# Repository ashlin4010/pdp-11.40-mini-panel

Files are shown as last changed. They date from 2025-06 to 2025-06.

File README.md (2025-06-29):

# PDP-11/40 Mini Panel (Unfinished)
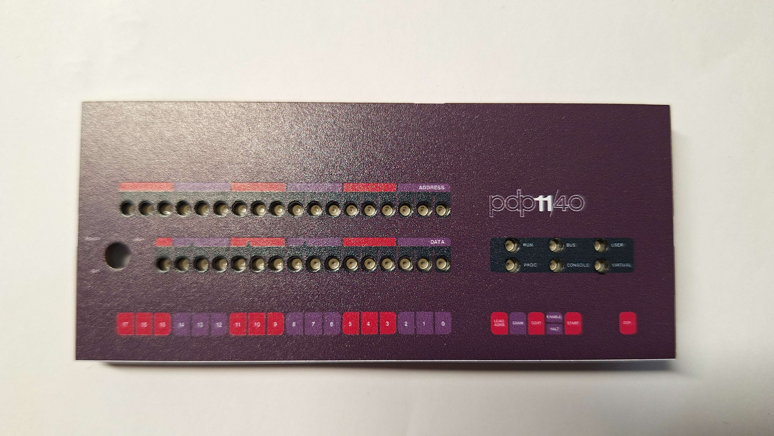
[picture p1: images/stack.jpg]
mini front panel


Included in this repository are the PCB files to make a miniature PDP-11/40 front panel. The board uses a XIAO nrf52840 dev board. No software has been written yet.

# Ordering pcbs
This project consists of three pcbs:
- A faceplate - Decorative only
    - pdp-11-colour.zip
    - 2 layers
    - PCB Color: White
    - Silkscreen Technology: EasyEDA multi-color silkscreen
- Main PCB - Has all electronics
    - pdp-11-pcb.zip
    - 4 layers
- Spacer PCB (Optional) - Removes the need for hot air
    - XIAO-nRF52840-spacer_thin.zip
    - 2 layers
    - Thickness: 0.8m
    - Deburring/Edge rounding: No

# Building
Place the spacer on the back of the nrf52840 module with the pads facing the the front. Solder the spacer to the back of the module using a minimal amount of solder. File the solder pints flat if needed.

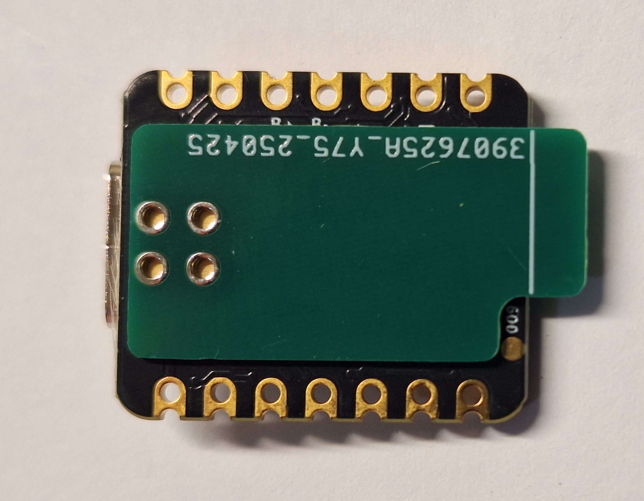
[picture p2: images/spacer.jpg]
pcb spacer


Solder the module and spacer to the main PCB. Using some short wire solder the pads of the space to the main PCB. Skip the top most pad, its ground.

For the programming header orientation check [main pcb image](/images/pcb_back.jpg).

# Programming
¯\\_(ツ)_/¯

# BOM

| Quantity | Part | Link |
|---|---|---|
| 1 | mini nrf52840 | https://www.aliexpress.com/item/1005008563470913.html |
| 1 | 3.3V 1A SOT-223 Reg | https://www.digikey.co.nz/en/products/detail/texas-instruments/TLV1117LV33DCYR/2666508 |
| 40 | Red LED LSP47K | https://www.digikey.co.nz/en/products/detail/ams-osram-usa-inc/LS-P47K-H1K2-1-0-2-R18-Z/1227985 |
| 2 | 1uf 0805 | https://www.digikey.co.nz/en/products/detail/samsung-electro-mechanics/CL21B105KAFNNNE/3886724  |
| 5 | 74HC595PW | https://www.digikey.co.nz/en/products/detail/nexperia-usa-inc/74HC595PW-118/946653 |
| 40 | 150R 0805 | https://www.digikey.co.nz/en/products/detail/yageo/RC0805JR-07150RL/728255 |
| 2 | 100R 0805 | https://www.digikey.co.nz/en/products/detail/yageo/RC0805JR-10100RL/14286702 |
| 1 | Programming Header  | https://www.digikey.co.nz/en/products/detail/adafruit-industries-llc/4048/9843412 |
| 1 | Expansion Header | https://www.digikey.co.nz/en/products/detail/adam-tech/HRS-2C-16-G-SMT-P/10245144 |

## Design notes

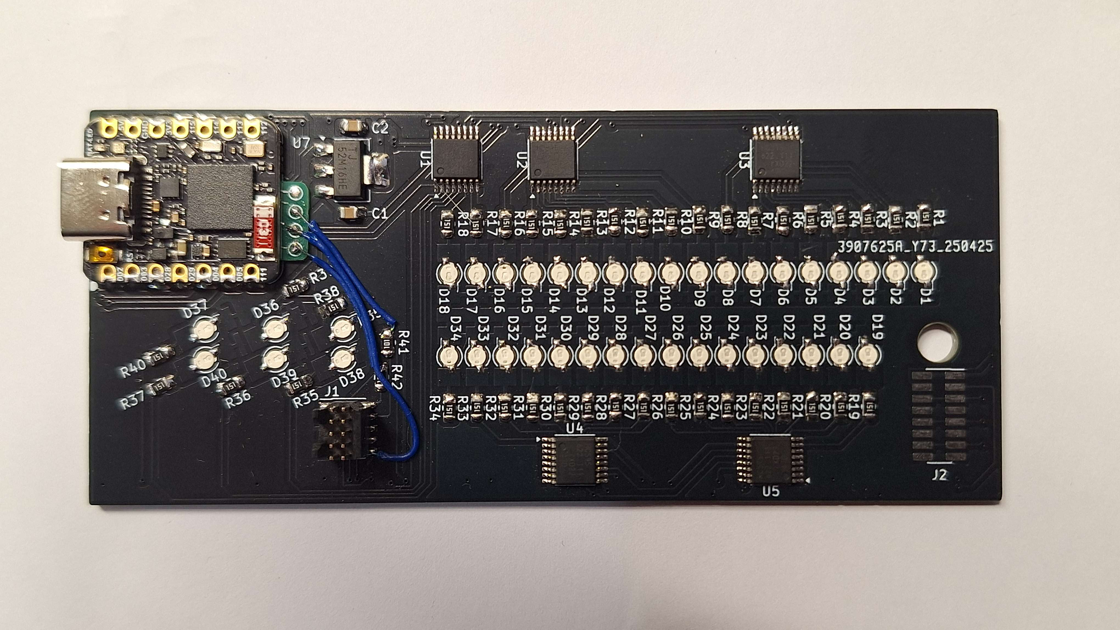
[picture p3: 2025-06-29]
images/pcb_back.jpg

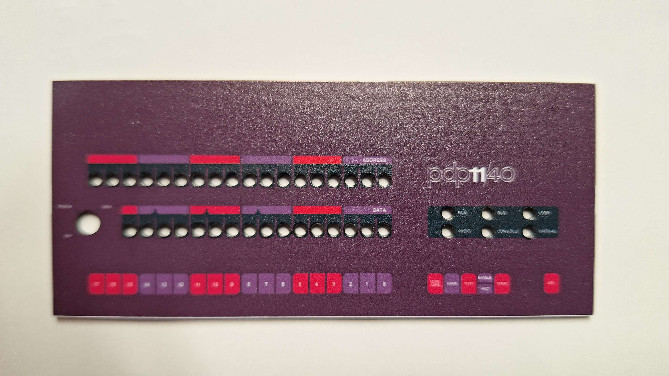
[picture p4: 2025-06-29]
images/faceplate.jpg

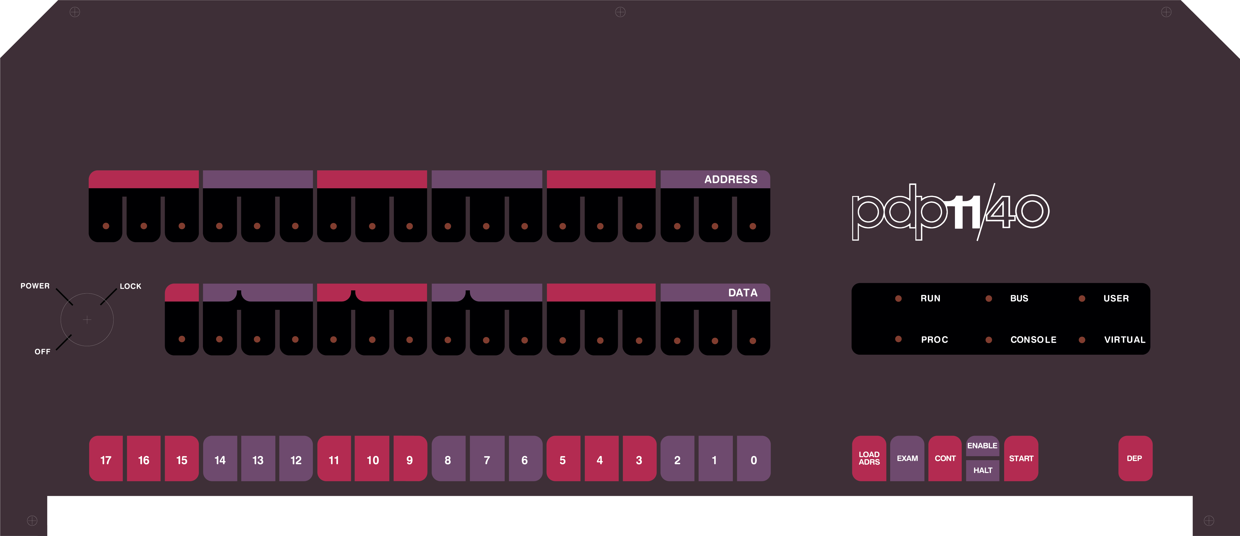
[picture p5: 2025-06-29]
art/PDP11.40_ref.png

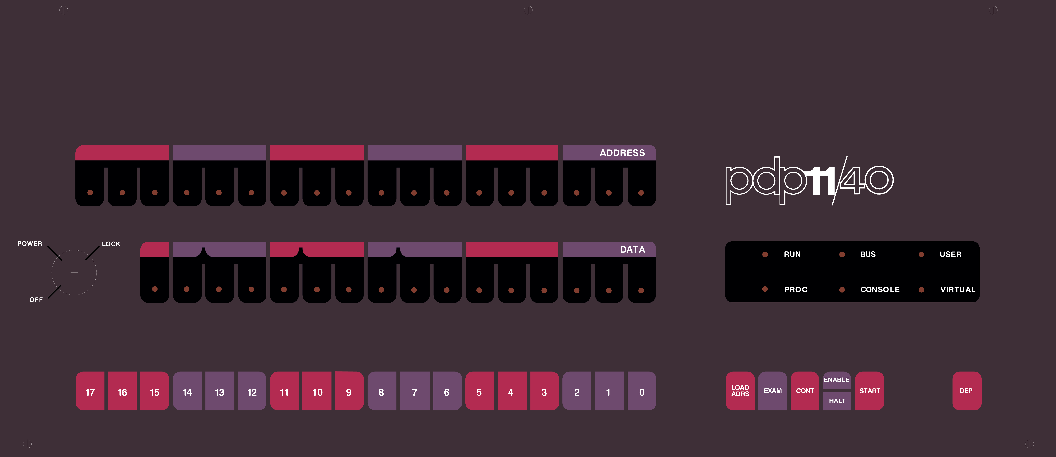
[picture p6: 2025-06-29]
art/PDP11.40_panel_600dpi.png

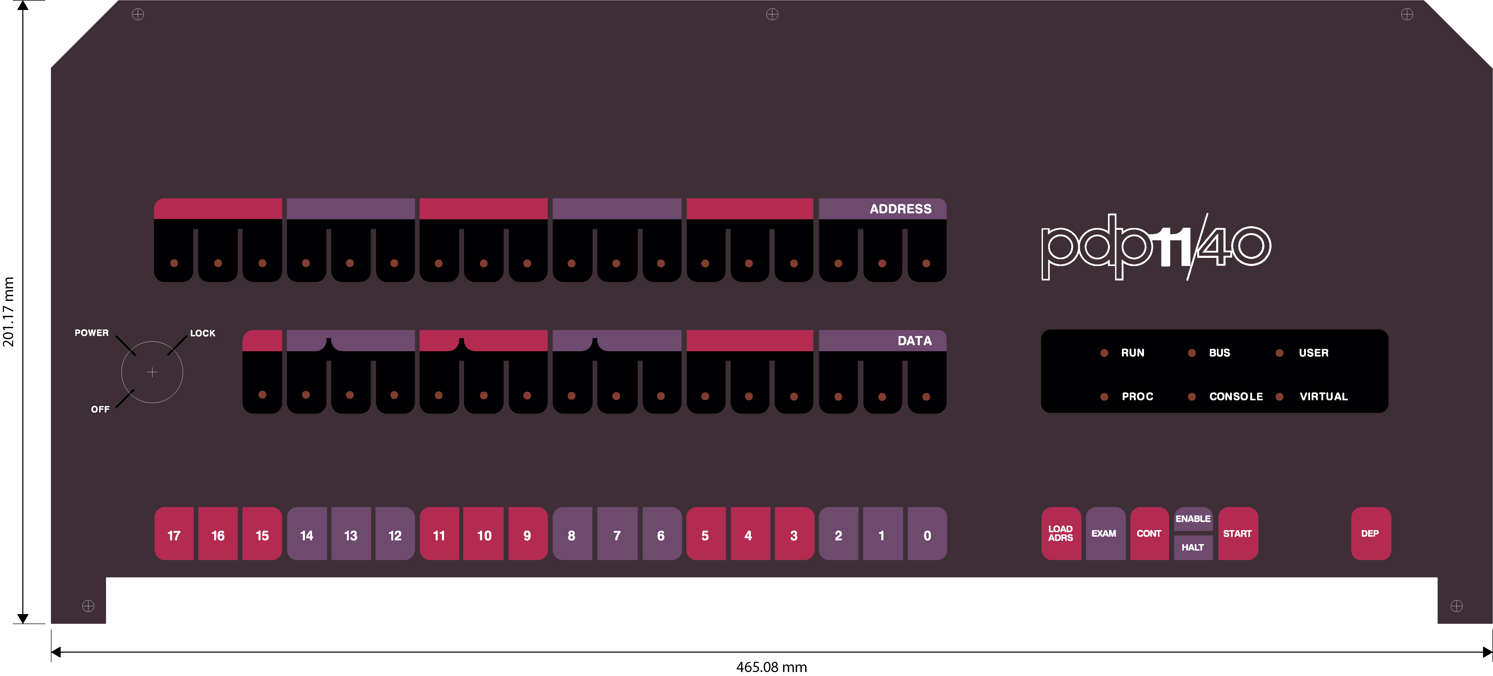
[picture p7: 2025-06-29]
art/PDP11.40_panel_size.png

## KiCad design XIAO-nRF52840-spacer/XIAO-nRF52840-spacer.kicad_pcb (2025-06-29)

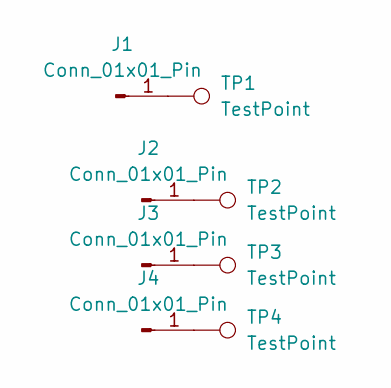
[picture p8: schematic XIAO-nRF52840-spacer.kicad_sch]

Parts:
J1, J2, J3, J4: Conn_01x01_Pin; PinHole
TP1, TP2, TP3, TP4: TestPoint; TestPoint_Pad_D1.0mm

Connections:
unnamed: J1.1, TP1.1
unnamed: J2.1, TP2.1
unnamed: J3.1, TP3.1
unnamed: J4.1, TP4.1

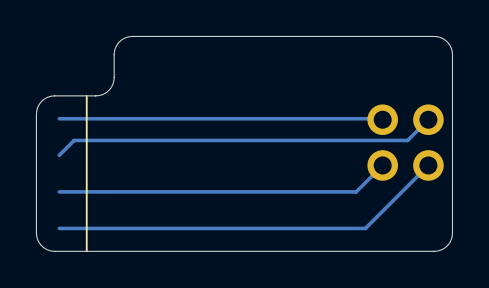
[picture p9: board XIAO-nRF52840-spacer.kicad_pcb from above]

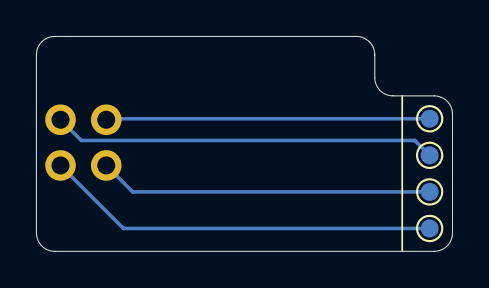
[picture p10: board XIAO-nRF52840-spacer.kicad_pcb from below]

Board: 2 copper layers, 23.1 x 11.9 mm, 8 parts (4 on the bottom side), 4 nets.

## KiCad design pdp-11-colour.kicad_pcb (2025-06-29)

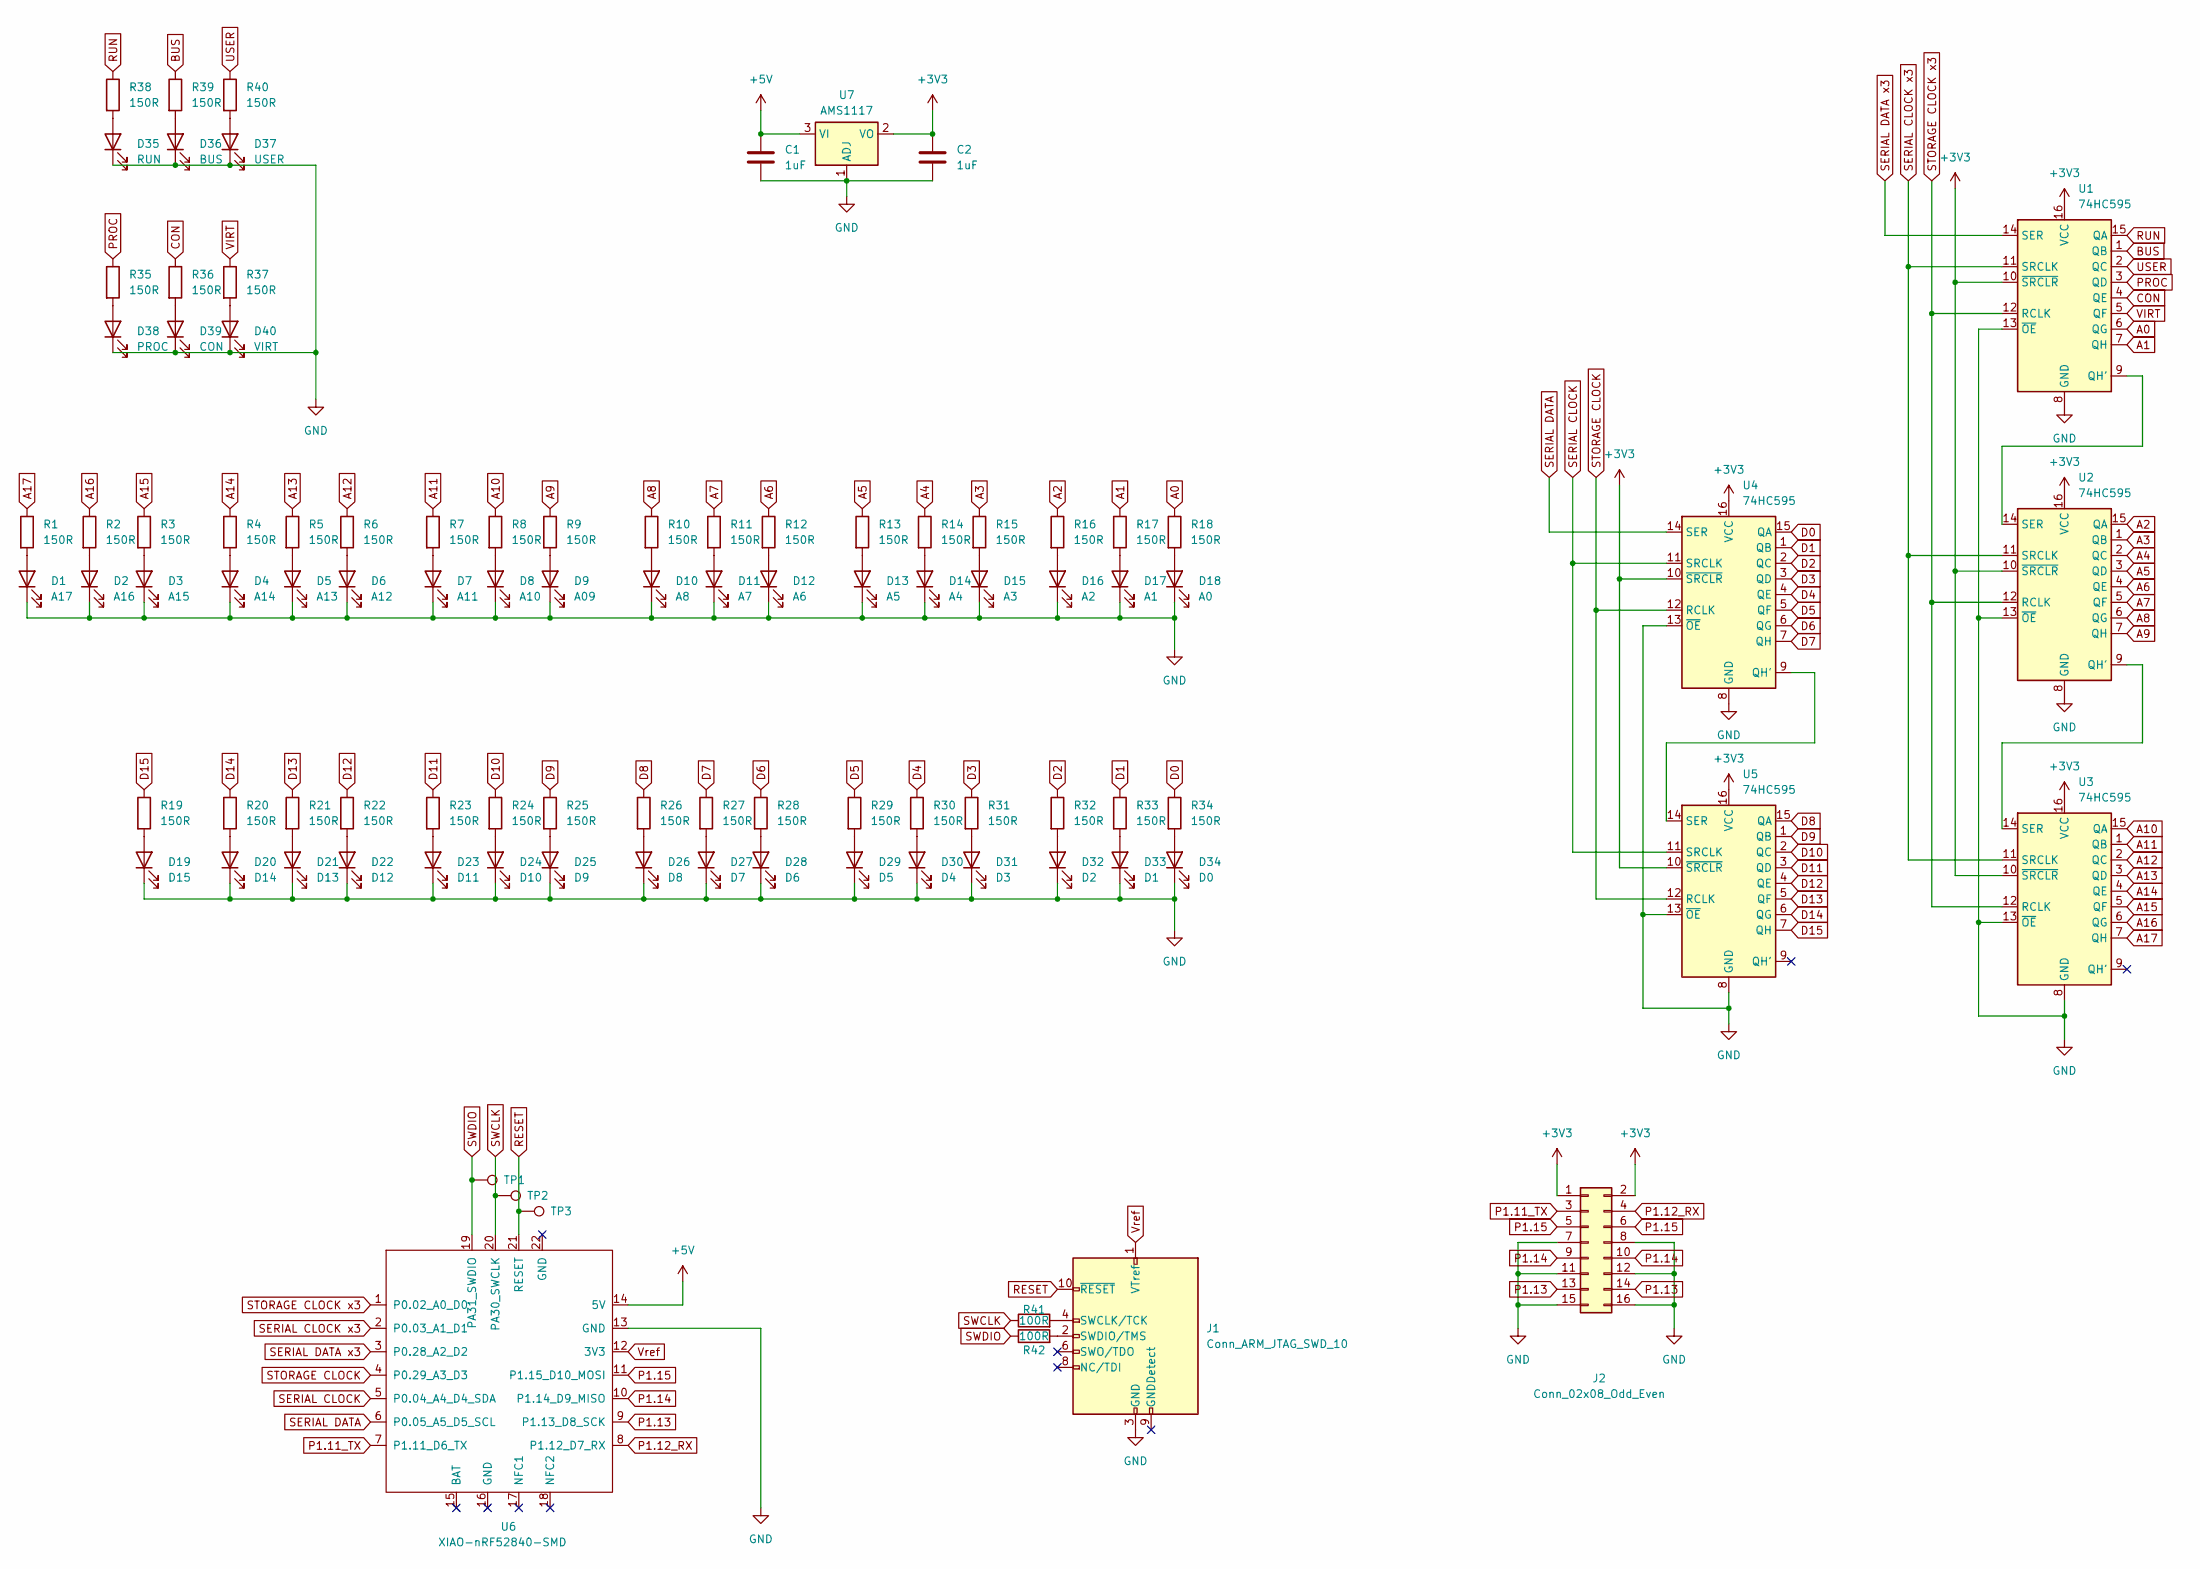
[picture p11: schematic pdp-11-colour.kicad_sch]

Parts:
C1, C2: 1uF; C_0805_2012Metric_Pad1.18x1.45mm_HandSolder
D1: A17; LED_Osram_Lx_P47F_D2mm_ReverseMount
D2: A16; LED_Osram_Lx_P47F_D2mm_ReverseMount
D3: A15; LED_Osram_Lx_P47F_D2mm_ReverseMount
D4: A14; LED_Osram_Lx_P47F_D2mm_ReverseMount
D5: A13; LED_Osram_Lx_P47F_D2mm_ReverseMount
D6: A12; LED_Osram_Lx_P47F_D2mm_ReverseMount
D7: A11; LED_Osram_Lx_P47F_D2mm_ReverseMount
D8: A10; LED_Osram_Lx_P47F_D2mm_ReverseMount
D9: A09; LED_Osram_Lx_P47F_D2mm_ReverseMount
D10: A8; LED_Osram_Lx_P47F_D2mm_ReverseMount
D11: A7; LED_Osram_Lx_P47F_D2mm_ReverseMount
D12: A6; LED_Osram_Lx_P47F_D2mm_ReverseMount
D13: A5; LED_Osram_Lx_P47F_D2mm_ReverseMount
D14: A4; LED_Osram_Lx_P47F_D2mm_ReverseMount
D15: A3; LED_Osram_Lx_P47F_D2mm_ReverseMount
D16: A2; LED_Osram_Lx_P47F_D2mm_ReverseMount
D17: A1; LED_Osram_Lx_P47F_D2mm_ReverseMount
D18: A0; LED_Osram_Lx_P47F_D2mm_ReverseMount
D19: D15; LED_Osram_Lx_P47F_D2mm_ReverseMount
D20: D14; LED_Osram_Lx_P47F_D2mm_ReverseMount
D21: D13; LED_Osram_Lx_P47F_D2mm_ReverseMount
D22: D12; LED_Osram_Lx_P47F_D2mm_ReverseMount
D23: D11; LED_Osram_Lx_P47F_D2mm_ReverseMount
D24: D10; LED_Osram_Lx_P47F_D2mm_ReverseMount
D25: D9; LED_Osram_Lx_P47F_D2mm_ReverseMount
D26: D8; LED_Osram_Lx_P47F_D2mm_ReverseMount
D27: D7; LED_Osram_Lx_P47F_D2mm_ReverseMount
D28: D6; LED_Osram_Lx_P47F_D2mm_ReverseMount
D29: D5; LED_Osram_Lx_P47F_D2mm_ReverseMount
D30: D4; LED_Osram_Lx_P47F_D2mm_ReverseMount
D31: D3; LED_Osram_Lx_P47F_D2mm_ReverseMount
D32: D2; LED_Osram_Lx_P47F_D2mm_ReverseMount
D33: D1; LED_Osram_Lx_P47F_D2mm_ReverseMount
D34: D0; LED_Osram_Lx_P47F_D2mm_ReverseMount
D35: RUN; LED_Osram_Lx_P47F_D2mm_ReverseMount
D36: BUS; LED_Osram_Lx_P47F_D2mm_ReverseMount
D37: USER; LED_Osram_Lx_P47F_D2mm_ReverseMount
D38: PROC; LED_Osram_Lx_P47F_D2mm_ReverseMount
D39: CON; LED_Osram_Lx_P47F_D2mm_ReverseMount
D40: VIRT; LED_Osram_Lx_P47F_D2mm_ReverseMount
J1: Conn_ARM_JTAG_SWD_10; PinHeader_2x05_P1.27mm_Vertical_SMD
J2: Conn_02x08_Odd_Even; PinSocket_2x08_P1.27mm_Vertical_SMD
R1, R2, R3, R4, R5, R6, R7, R8, R9, R10, R11, R12, R13, R14, R15, R16, R17, R18, R19, R20, R21, R22, R23, R24, R25, R26, R27, R28, R29, R30, R31, R32, R33, R34, R35, R36, R37, R38, R39, R40: 150R; R_0805_2012Metric_Pad1.20x1.40mm_HandSolder
R41, R42: 100R; R_0805_2012Metric_Pad1.20x1.40mm_HandSolder
TP1, TP2, TP3: TestPoint; TestPoint_Pad_D1.0mm
U1, U2, U3, U4, U5: 74HC595; TSSOP-16_4.4x5mm_P0.65mm
U6: XIAO-nRF52840-SMD
U7: AMS1117; SOT-223-3_TabPin2

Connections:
+3V3: C2.1, J2.1, J2.2, U1.10 (~SRCLR), U1.16 (VCC), U2.10 (~SRCLR), U2.16 (VCC), U3.10 (~SRCLR), U3.16 (VCC), U4.10 (~SRCLR), U4.16 (VCC), U5.10 (~SRCLR), U5.16 (VCC), U7.2 (VO)
+5V: C1.1, U6.14 (5V), U7.3 (VI)
A0: R18.1, U1.6 (QG)
A1: R17.1, U1.7 (QH)
A2: R16.1, U2.15 (QA)
A3: R15.1, U2.1 (QB)
A4: R14.1, U2.2 (QC)
A5: R13.1, U2.3 (QD)
A6: R12.1, U2.4 (QE)
A7: R11.1, U2.5 (QF)
A8: R10.1, U2.6 (QG)
A9: R9.1, U2.7 (QH)
A10: R8.1, U3.15 (QA)
A11: R7.1, U3.1 (QB)
A12: R6.1, U3.2 (QC)
A13: R5.1, U3.3 (QD)
A14: R4.1, U3.4 (QE)
A15: R3.1, U3.5 (QF)
A16: R2.1, U3.6 (QG)
A17: R1.1, U3.7 (QH)
BUS: R39.1, U1.1 (QB)
CON: R36.1, U1.4 (QE)
D0: R34.1, U4.15 (QA)
D1: R33.1, U4.1 (QB)
D2: R32.1, U4.2 (QC)
D3: R31.1, U4.3 (QD)
D4: R30.1, U4.4 (QE)
D5: R29.1, U4.5 (QF)
D6: R28.1, U4.6 (QG)
D7: R27.1, U4.7 (QH)
D8: R26.1, U5.15 (QA)
D9: R25.1, U5.1 (QB)
D10: R24.1, U5.2 (QC)
D11: R23.1, U5.3 (QD)
D12: R22.1, U5.4 (QE)
D13: R21.1, U5.5 (QF)
D14: R20.1, U5.6 (QG)
D15: R19.1, U5.7 (QH)
GND: C1.2, C2.2, D1.1 (K), D2.1 (K), D3.1 (K), D4.1 (K), D5.1 (K), D6.1 (K), D7.1 (K), D8.1 (K), D9.1 (K), D10.1 (K), D11.1 (K), D12.1 (K), D13.1 (K), D14.1 (K), D15.1 (K), D16.1 (K), D17.1 (K), D18.1 (K), D19.1 (K), D20.1 (K), D21.1 (K), D22.1 (K), D23.1 (K), D24.1 (K), D25.1 (K), D26.1 (K), D27.1 (K), D28.1 (K), D29.1 (K), D30.1 (K), D31.1 (K), D32.1 (K), D33.1 (K), D34.1 (K), D35.1 (K), D36.1 (K), D37.1 (K), D38.1 (K), D39.1 (K), D40.1 (K), J1.3 (GND), J1.5 (GND), J2.7, J2.8, J2.11, J2.12, J2.15, J2.16, U1.8 (GND), U1.13 (~OE), U2.8 (GND), U2.13 (~OE), U3.8 (GND), U3.13 (~OE), U4.8 (GND), U4.13 (~OE), U5.8 (GND), U5.13 (~OE), U6.13 (GND), U7.1 (ADJ)
unnamed: D1.2 (A), R1.2
unnamed: D2.2 (A), R2.2
unnamed: D3.2 (A), R3.2
unnamed: D4.2 (A), R4.2
unnamed: D5.2 (A), R5.2
unnamed: D6.2 (A), R6.2
unnamed: D7.2 (A), R7.2
unnamed: D8.2 (A), R8.2
unnamed: D9.2 (A), R9.2
unnamed: D10.2 (A), R10.2
unnamed: D11.2 (A), R11.2
unnamed: D12.2 (A), R12.2
unnamed: D13.2 (A), R13.2
unnamed: D14.2 (A), R14.2
unnamed: D15.2 (A), R15.2
unnamed: D16.2 (A), R16.2
unnamed: D17.2 (A), R17.2
unnamed: D18.2 (A), R18.2
unnamed: D19.2 (A), R19.2
unnamed: D20.2 (A), R20.2
unnamed: D21.2 (A), R21.2
unnamed: D22.2 (A), R22.2
unnamed: D23.2 (A), R23.2
unnamed: D24.2 (A), R24.2
unnamed: D25.2 (A), R25.2
unnamed: D26.2 (A), R26.2
unnamed: D27.2 (A), R27.2
unnamed: D28.2 (A), R28.2
unnamed: D29.2 (A), R29.2
unnamed: D30.2 (A), R30.2
unnamed: D31.2 (A), R31.2
unnamed: D32.2 (A), R32.2
unnamed: D33.2 (A), R33.2
unnamed: D34.2 (A), R34.2
unnamed: D35.2 (A), R38.2
unnamed: D36.2 (A), R39.2
unnamed: D37.2 (A), R40.2
unnamed: D38.2 (A), R35.2
unnamed: D39.2 (A), R36.2
unnamed: D40.2 (A), R37.2
unnamed: J1.4 (SWCLK/TCK), R41.2
unnamed: J1.2 (SWDIO/TMS), R42.2
unnamed: U1.9 (QH'), U2.14 (SER)
unnamed: U2.9 (QH'), U3.14 (SER)
unnamed: U4.9 (QH'), U5.14 (SER)
P1.11_TX: J2.3, U6.7 (P1.11_D6_TX)
P1.12_RX: J2.4, U6.8 (P1.12_D7_RX)
P1.13: J2.13, J2.14, U6.9 (P1.13_D8_SCK)
P1.14: J2.9, J2.10, U6.10 (P1.14_D9_MISO)
P1.15: J2.5, J2.6, U6.11 (P1.15_D10_MOSI)
PROC: R35.1, U1.3 (QD)
RESET: J1.10 (~RESET), TP3.1, U6.21 (RESET)
RUN: R38.1, U1.15 (QA)
SERIAL CLOCK: U4.11 (SRCLK), U5.11 (SRCLK), U6.5 (P0.04_A4_D4_SDA)
SERIAL CLOCK x3: U1.11 (SRCLK), U2.11 (SRCLK), U3.11 (SRCLK), U6.2 (P0.03_A1_D1)
SERIAL DATA: U4.14 (SER), U6.6 (P0.05_A5_D5_SCL)
SERIAL DATA x3: U1.14 (SER), U6.3 (P0.28_A2_D2)
STORAGE CLOCK: U4.12 (RCLK), U5.12 (RCLK), U6.4 (P0.29_A3_D3)
STORAGE CLOCK x3: U1.12 (RCLK), U2.12 (RCLK), U3.12 (RCLK), U6.1 (P0.02_A0_D0)
SWCLK: R41.1, TP2.1, U6.20 (PA30_SWCLK)
SWDIO: R42.1, TP1.1, U6.19 (PA31_SWDIO)
USER: R40.1, U1.2 (QC)
VIRT: R37.1, U1.5 (QF)
Vref: J1.1 (VTref), U6.12 (3V3)

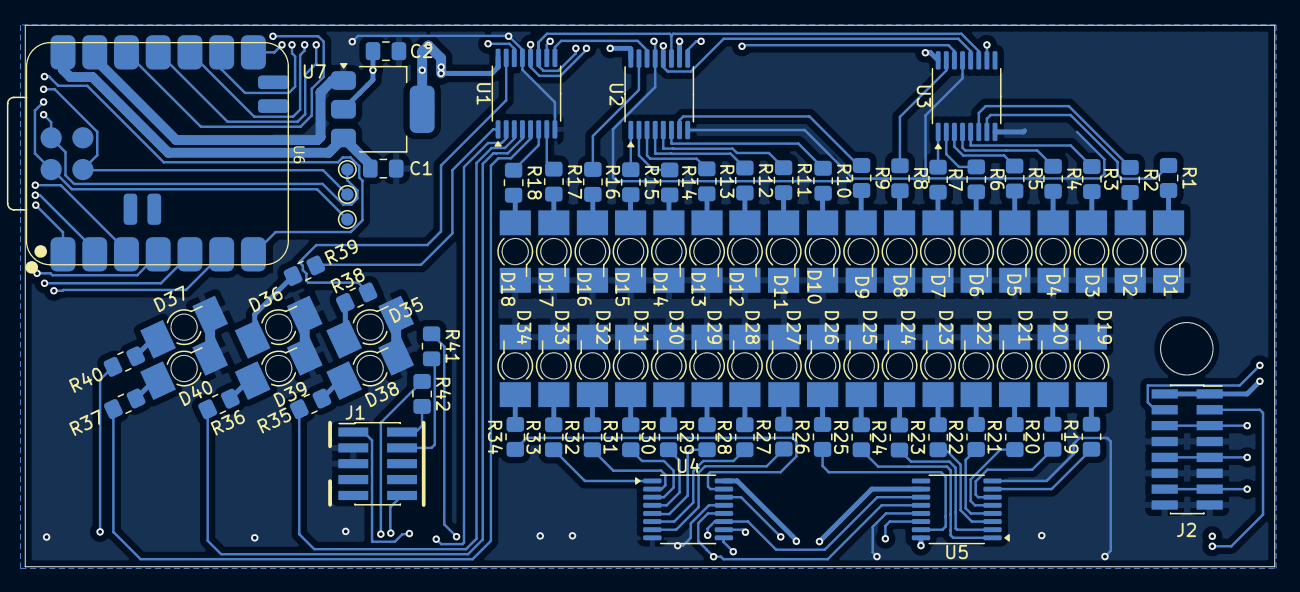
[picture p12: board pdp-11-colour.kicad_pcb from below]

Board: 4 copper layers, 100.0 x 43.3 mm, 96 parts (96 on the bottom side), 103 nets.
